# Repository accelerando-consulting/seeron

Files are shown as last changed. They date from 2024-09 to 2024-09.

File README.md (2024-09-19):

# The Eye of Seeron

A better illuminated loupe for inspecting circuit boards.

I bought [this loupe](https://s.click.aliexpress.com/e/_Dc7G7sf) for
inspecting circuit boards, because of its built in LEDs.   But there
is a risk of depleting the coin cell batteries if it is left on, so I 
wanted to fit a rechargeable power source.   I began by attempting to
modify the existing circuitry, but it is extremely difficult to solder
to the existing circuit board, due to it being surrounded by a welded
plastic shell.

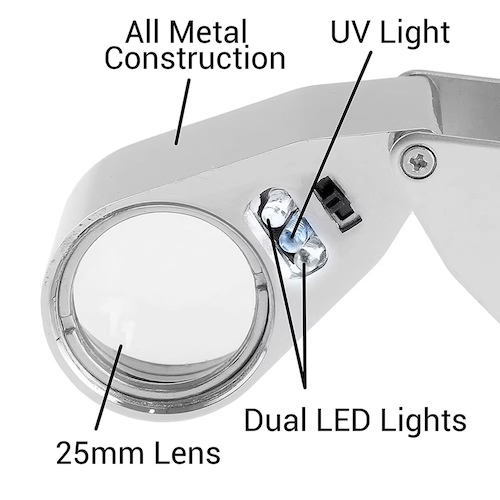
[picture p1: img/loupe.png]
Loupe with built in light


So I removed the existing circuitry and LEDs entirely and created a
ring-light that fits underneath the existing lens retaining ring.

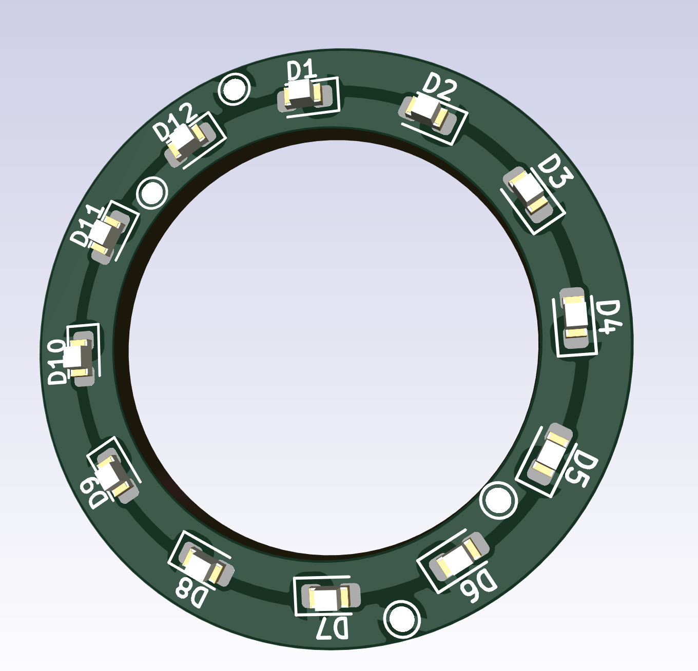
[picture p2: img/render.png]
3D render of circuit board


You will need some way of limiting the current draw to no more than
about 200mA.  Either fit a resistor in series with the battery, or
stay tuned for my auto-off control circuit.

The circuit needs up to twelve surface mount Light-Emitting Diodes
(LED) in size 0603.   I used six normal LEDs ([LCSC part C965808](https://www.lcsc.com/product-detail/LED-Indication-Discrete_XINGLIGHT-XL-1608UWC-04_C965808.html))
 and six side-emitting type ([LCSC part
 C273618](https://www.lcsc.com/product-detail/LED-Indication-Discrete_TOGIALED-TJ-S1706SW6TGLCCW-A5_C273618.html).
 
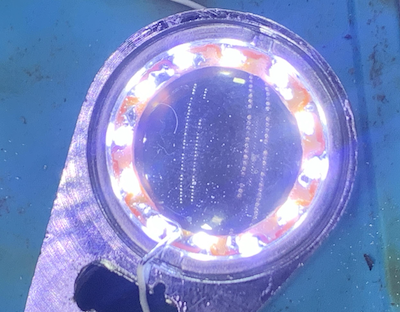
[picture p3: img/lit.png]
Illuminated ringlight


## I want to make one 

You can upload the gerbers.zip file to JLCPCB to have this made, or
use the mill_gerbers.zip to cut your own on a CNC mill.

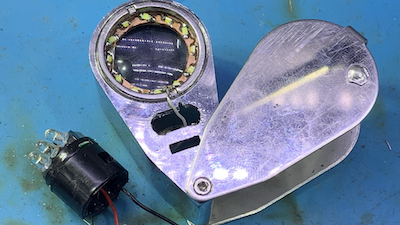
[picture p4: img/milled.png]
Milled circuit board


You can find instructions for the milling process [here](https://accelerando.com.au/news/2021/07/how-we-make-fast-prototypes-at-accelerando-part-1-pcbs/).

## Can I just buy one off you?

Soon.
.

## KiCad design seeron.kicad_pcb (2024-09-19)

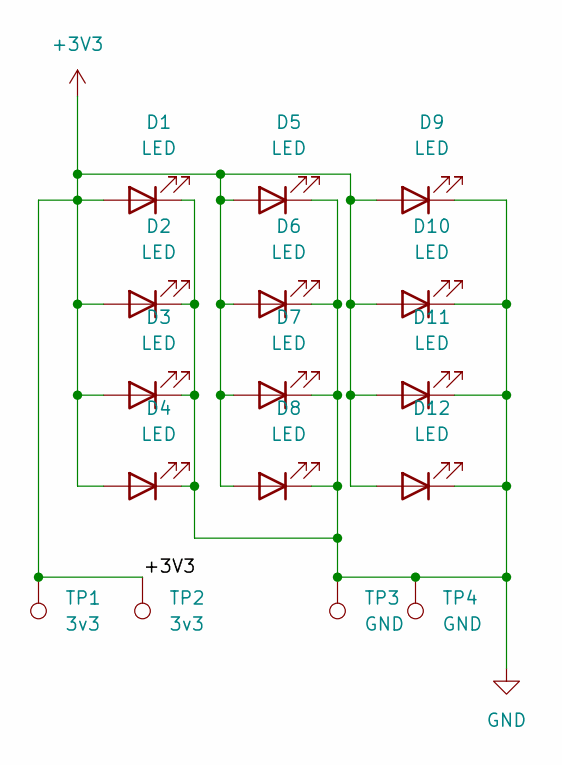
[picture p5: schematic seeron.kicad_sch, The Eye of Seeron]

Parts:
D1, D2, D3, D4, D5, D6, D7, D8, D9, D10, D11, D12: LED; LED_0603_1608Metric
TP1, TP2: 3v3; TestPoint_Pad_D1.0mm
TP3, TP4: GND; TestPoint_Pad_D1.0mm

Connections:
+3V3: D1.2 (A), D2.2 (A), D3.2 (A), D4.2 (A), D5.2 (A), D6.2 (A), D7.2 (A), D8.2 (A), D9.2 (A), D10.2 (A), D11.2 (A), D12.2 (A), TP1.1, TP2.1
GND: D1.1 (K), D2.1 (K), D3.1 (K), D4.1 (K), D5.1 (K), D6.1 (K), D7.1 (K), D8.1 (K), D9.1 (K), D10.1 (K), D11.1 (K), D12.1 (K), TP3.1, TP4.1

Board: 2 copper layers, 16 parts (0 on the bottom side), 2 nets, no tracks yet.

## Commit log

2024-09-19 Single sided ringlight PCB for 25.4mm loupe
    [seeron.kicad_pcb, seeron.kicad_sch]
2024-09-19 Add readme and more test points for providing power contacts if solder mask is used
    [seeron.kicad_pcb, seeron.kicad_sch]
